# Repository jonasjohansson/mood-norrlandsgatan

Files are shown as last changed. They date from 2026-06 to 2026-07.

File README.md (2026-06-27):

# Mood Norrlandsgatan — "People in Orbit"

CAD + browser tooling for the **AMF / Mood Gallerian** entrance light installation
(Norrlandsgatan, Stockholm), replacing Peter Hagdahl's *Liquid Sky*. Glowing
human-like bodies that orbit the entrance columns, made of LED-in-silicone flex
pushed into a **glossy snap-groove host**, bracketed to the **existing ceiling
steel profiles**. Canopy ≈ **9 × 5 m**. Brief: 10-yr life, low maintenance, fire
(PBL — bygglov granted).

## Settled spec (assumptions until supplier confirms)
- **Light:** FN-ESJT-B0612 **6×12 COB**, **white LED in coloured silicone** — colour
  is a stable pigment, no RGB controller (the *Liquid Sky* lesson: minimal electronics).
  Fixed colour per figure; 2-core + white driver. Min bend radius assumed **90 mm**.
- **Host:** glossy panel with a routed **dovetail snap-groove** (undercut grips the
  6 mm foot; 12 mm body + dome hang down, light into the room).
- **Material:** exterior **compact phenolic** (Trespa Meteon / Fundermax), high-gloss
  — outdoor/UV/fire-rated, routable.
- **Cut:** **Shaper Origin** + dovetail bit, on-line along the figure paths.
- **Mount:** brackets to the existing steel profiles; modules with expansion gaps.

## The loop
```
figure .ai ─▶ Bend Lab (edit shape, all-green) ─▶ paths.json
   ─▶ shaper.py (1:1 dovetail-groove SVG)  ─▶ Shaper Origin cut
   ─▶ figure.py (3D canopy preview) · order.py (cut list / BOM)
```

## Layout
```
cad/
  channel.py    core params (HostParams = 6x12 profile), snap-groove, neon, coupon
  detail.py     engineering detail: dovetail snap + bracket + steel profile
  options.py    mounting-option comparison (groove vs alu track vs clips)
  figure.py     full 9x5 m canopy module -> STL/STEP + manifest (reads paths.json)
  svgcheck.py   bend-radius check on a figure SVG -> overlay + paths.json
  shaper.py     1:1 mm Shaper Origin cut SVGs (on-line dovetail grooves)
  order.py      procurement cut list: metres per colour, segments, power
  calibrate.py  neon snap-fit coupons across slot clearances
  render.py     headless STL -> PNG
  index.html    3D viewer (light, static): toggles + explode
  bendlab.html  SHAPE + BEND editor: load/draw, edit anchors, smoothing slider,
                break-at-fingers, live bend check, export SVG + paths.json
  ideate.html   (optional) freehand pattern sketcher
  out/          exports + manifest.json + order.csv  (gitignored)
```

## Use
Served by the local web server (docroot = `~/Documents/GitHub`):
```
  bend lab:  http://localhost/mood-norrlandsgatan/cad/bendlab.html   (edit a figure -> Export)
  3D view:   http://localhost/mood-norrlandsgatan/cad/               (run figure.py first)
  bend map:  http://localhost/mood-norrlandsgatan/cad/out/check_<name>.svg
```
```sh
cd cad
uv run python figure.py         # canopy preview  (or detail.py for the snap detail)
uv run python shaper.py         # 1:1 groove SVGs for the Origin
uv run python order.py          # cut list / bill of materials
uv run python calibrate.py      # snap-fit coupons to tune the push-fit
```

## Parameters (`cad/channel.py` → `HostParams`, mm)
| param | default | meaning |
|---|---|---|
| `neon_w` / `neon_h` | 6 / 12 | FN-ESJT-B0612 foot width / full height |
| `foot` / `slot_depth` | 5 / 5 | foot gripped in the groove / groove depth |
| `slot_clr` | 0.4 | per-side push-fit clearance — **tune with `calibrate.py`** |
| `lip` | 1.0 | undercut retaining lip (dovetail bit) |
| `panel_t` | 12 | glossy host thickness |

## To confirm with the supplier / site
- [ ] FN-ESJT-B0612 **COB availability**, **silicone jacket colours**, IP rating, **real min bend radius**.
- [ ] White LED **CCT** (tunes the filtered colour) + output (colour filter costs brightness).
- [ ] Steel-profile section/spacing on site → bracket type + `PROFILE_YS`.
- [ ] Real figures: edit in Bend Lab to all-green, export `paths.json`.
- [ ] Sweep the dovetail groove along curved paths (today exact only on the straight detail/coupon).

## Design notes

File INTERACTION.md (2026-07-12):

# Interaction — touch the pillars, the figures come alive

## Concept
A conductive **hand-sign plate** on each of the 2 entrance pillars. The figures **rest at
~50% brightness** all the time; place a hand on a plate and they **rise to ~90% and hold**
there while the hand rests, easing back to 50% when it lifts. A short onset ripple sweeps up
from the touched pillar as the light rushes in. Non-addressable coloured neon, animated by
**per-figure brightness (PWM)** — colours stay fixed, motion is in the dimming.

Presence is continuous (force sensing), so this is a level, not a trigger: partial pressure
could even map to a partial lift between 50% and 90%. Tunable live in the viewer via
**Neon → Rest level / Touch level**.

## Sensor — force sensing (hand rests with slight pressure)
Requirements: detect a hand *placed/resting*, **works with gloves**, bulletproof, IP-rated,
lasts years outdoors. -> **load cell / strain gauge behind the aluminium plate**
(HX711 amp -> ESP32), or an industrial piezo force switch for simple on/off.
- Gloves: irrelevant (mechanical force, not capacitance/optics).
- Weatherproof/vandal-proof: sensor fully sealed behind the solid plate; nothing exposed;
  millions of cycles.
- Continuous force -> detects presence *while held*; press hard = optional intensity map.
- Firmware auto-tracks baseline (zeroes plate weight + thermal drift), fires on threshold.
- NOT a no-contact hover (that needs optical/ToF, whose window fouls over years).

## Electrical topology
    pillar plate ─ load cell ─ HX711 ─ sensor ESP32 (at pillar) ─ ESP-NOW ─┐
                                                                           ▼
    24 V PSU(s) ──▶ 8-ch MOSFET board (main ESP32, LEDC PWM) ──▶ figure channels
                         ▲ per-figure feeds converge here (see channels.json)

- Put the sensor node **at the pillar** (short load-cell lead); send touch events to the
  ceiling controller over **ESP-NOW** (no data cable up the pillar).
- Main ESP32 in the plenum drives one logic-level MOSFET per channel (size ~10 A each).

## Channels (see `channels.py` / `out/channels.json`)
8 channels (7 figures + rings), ~1122 W / 47 A @ 24 V. Biggest: blue 8.2 A.

## Added BOM (interaction only)
- 1x main ESP32 + 8-ch logic-level MOSFET board (or 8 discrete IRLZ44N-class FETs + gate R)
- 2x pillar sensor node: ESP32 (or ESP8266) + HX711 + load cell/strain gauge
- 2x aluminium hand-sign plate + isolating standoffs + flexure/mount for the load cell
- IP67 enclosures, glands, a bit more DC cable to converge feeds at the MOSFET board

## Open items
- Confirm strip **W/m** from datasheet (tightens W/A above).
- Choose load cell range (a light hand press is ~1-5 kg-equivalent on the plate).
- Animation design: ripple-from-pillar, all-breathe, per-figure chase (all doable in PWM).

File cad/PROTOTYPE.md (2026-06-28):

# Mounting prototype — first physical test

Goal: prove the **snap-fit** and the **bend** before cutting a full sheet.

## You need
- A **panel offcut** — ideally the real exterior compact phenolic (Trespa/Fundermax);
  any flat board (MDF/acrylic) is fine for a first dry run.
- The **Shaper Origin** + a **dovetail bit** (undercut groove). For a quick first
  pass a straight bit ~0.5 mm under the flex width also friction-fits.
- A few metres of **FN-ESJT-B0612** (6×12 COB) — the actual flex.
- A **steel offcut** + a **bracket / channel-nut** (to test the connection + overhead hold).

## Cut the coupon
File: `out/shaper/coupon.svg` (1:1 mm) →
`http://localhost/mood-norrlandsgatan/cad/out/shaper/coupon.svg`
- Import to the Origin, **On-Line** cut, **Shaper Tape** to register.
- 3 straight grooves = dial in **bit + depth + fit**.
- Arcs **r=120 / 90 / 60 mm** = bend test (90 = assumed min; 60 should kink/fail).
- Start depth ~**6 mm** (grips the foot; dome stays proud). Adjust on the straights.

## Test
1. Push the flex into the straight grooves — find the depth/fit that **holds when held upside-down** (overhead is the real test).
2. Run the flex around the arcs — confirm **90 mm** is clean; note where it kinks.
3. Bolt the coupon to the steel offcut with the bracket; **hang it**, power the flex.
   Check: overhead hold, the glow/line look, and gloss reflection off the panel.

## Report back → bake into the model
Tell me what worked and I'll set it in `channel.py → HostParams`:
- the **bit** (width) and **groove depth** that held,
- the **real min bend radius** (set the Bend Lab slider + `svgcheck.py` to it),
- the **bracket type** + spacing that felt solid.

Then `calibrate.py` / `shaper.py` regenerate against the proven numbers.

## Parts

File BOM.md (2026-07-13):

# Electrical BOM — People in Orbit (24 V)

_Auto-generated by `bom.py` from the current design. Load: **1122 W / 46.8 A @ 24 V**, 112 m neon, 28 power feeds, 10 continuous runs, 570 clips._

## Load per channel (one PWM channel / MOSFET per colour)

| colour | length | power | current | feeds |
|---|---|---|---|---|
| blue |  19.7 m |  197 W |  8.2 A | 4 |
| green |  16.2 m |  162 W |  6.8 A | 4 |
| yellow  |  16.2 m |  162 W |  6.8 A | 4 |
| cyan |  15.5 m |  155 W |  6.4 A | 4 |
| pink |  11.7 m |  117 W |  4.9 A | 3 |
| orange  |  11.5 m |  115 W |  4.8 A | 4 |
| purple  |  11.4 m |  114 W |  4.8 A | 3 |
| rings |  10.0 m |  100 W |  4.2 A | 2 |
| **total** | **112 m** | **1122 W** | **46.8 A** | **28** |

## Power supplies

- **5 x Mean Well HLG-320H-24 (320 W, IP67, 24 V)** — 1600 W installed vs 1122 W load (~70 % loaded). Mount distributed up near the soffit, each feeding its local zone — keep 24 V DC runs short. Dimming is downstream (MOSFET PWM), so a plain constant-voltage supply is fine.

## Control

- **1 x ESP32** (ceiling) — 8x LEDC PWM -> 8 MOSFETs, common-anode (switch the 24 V return).
- **8 x IRLB3034PBF** logic-level N-MOSFET (or an 8-ch >=16 A trigger board) — blue channel peaks 8.2 A, so size gate drive + heatsinking for >=10 A.
- **2 x ESP32 + HX711 + load cell** at the pillars — force-sensing hand-plates, ESP-NOW to the ceiling node.

## Neon terminations & mounting

- **28 feed connectors** (IP67) at the injection points + **~20 end caps** for the run ends.
- **639 stainless back-clips** for the through-slot mounting (incl. spare).

## Cable (estimated — refine against final PSU placement)

- **~118 m** 2-core 2.5 mm2 for 24 V distribution (PSU -> 28 feeds).
- **~40 m** mains + fused spur to the 5 supplies.

## Rough cost (electronics only — excl. Trespa panels, aluminium structure, labour)

| item | est. |
|---|---|
| Neon 24 V silicone flex, coloured (per profile), +12 % | $314 |
| Mean Well HLG-320H-24 (320 W, IP67, 24 V) | $300 |
| ESP32 dev board (1 ceiling controller + 2 pillar sensors) | $24 |
| 8-ch logic-level MOSFET (IRLB3034PBF) + heatsinks/gate res. | $42 |
| Load cell + HX711 amp (per pillar) | $30 |
| IP67 neon feed connectors / end caps | $114 |
| Stainless back-clips (through-slot mounting) | $160 |
| 2-core DC distribution cable 2.5 mm2 | $130 |
| Mains cable + fused spur to PSUs | $56 |
| Heat-shrink, WAGO, ferrules, cable clips, misc | $120 |
| **subtotal** | **$1,290** |

_Order-of-magnitude USD; confirm against suppliers. Neon @ ~$2.5/m, PSU @ ~$60. Excludes the boards (Trespa), aluminium ceiling profiles, and install labour._

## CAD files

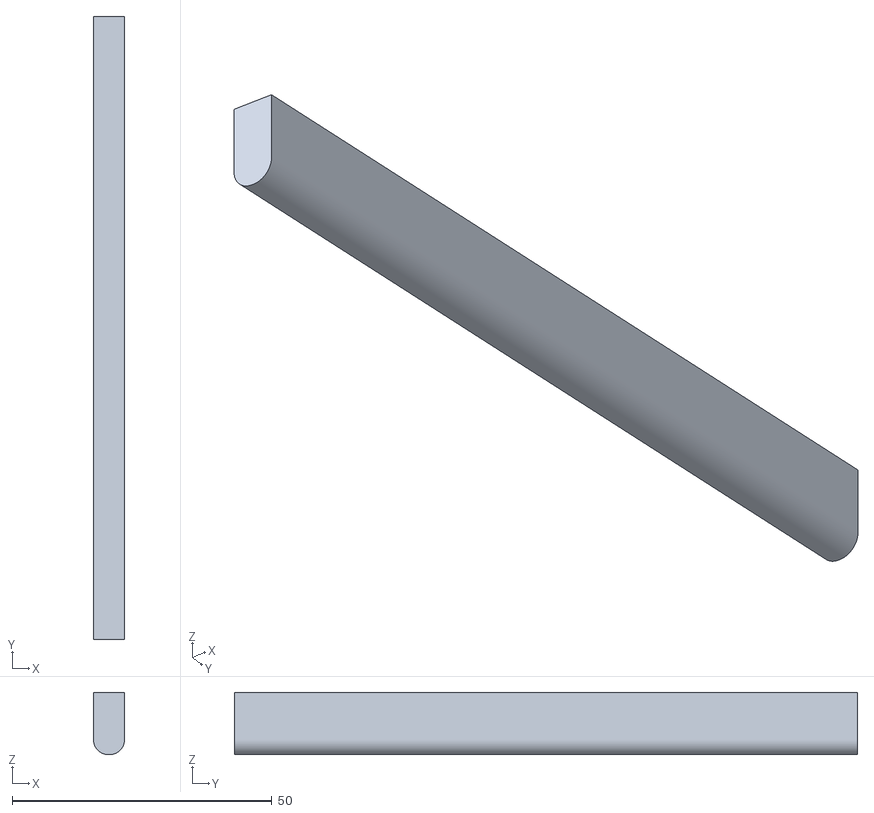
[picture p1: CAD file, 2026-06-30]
out/opt_C_neon.stl
6.00 x 120.0 x 12.0

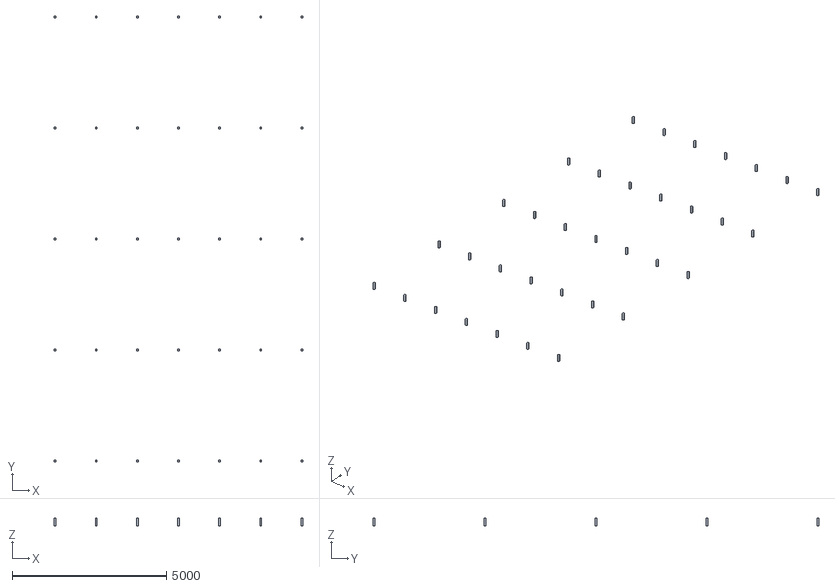
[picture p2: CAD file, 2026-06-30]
out/brackets.stl
8057.5 x 14455.3 x 250.0

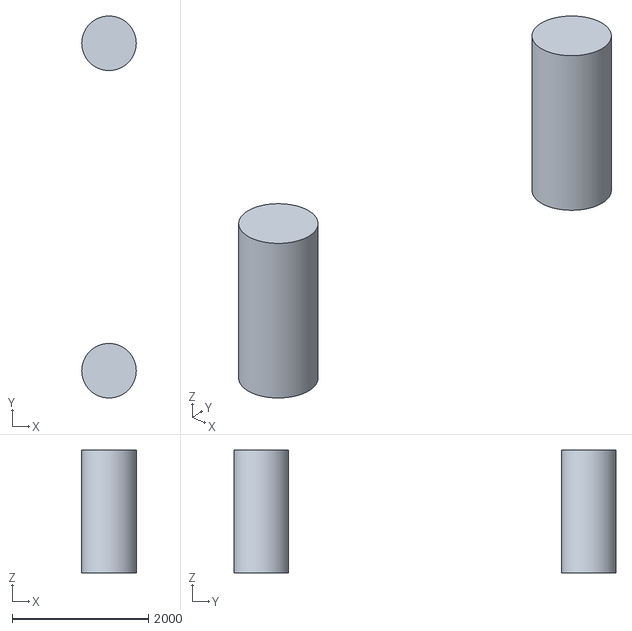
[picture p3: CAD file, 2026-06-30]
out/columns.stl
800.0 x 5602.8 x 1800.0

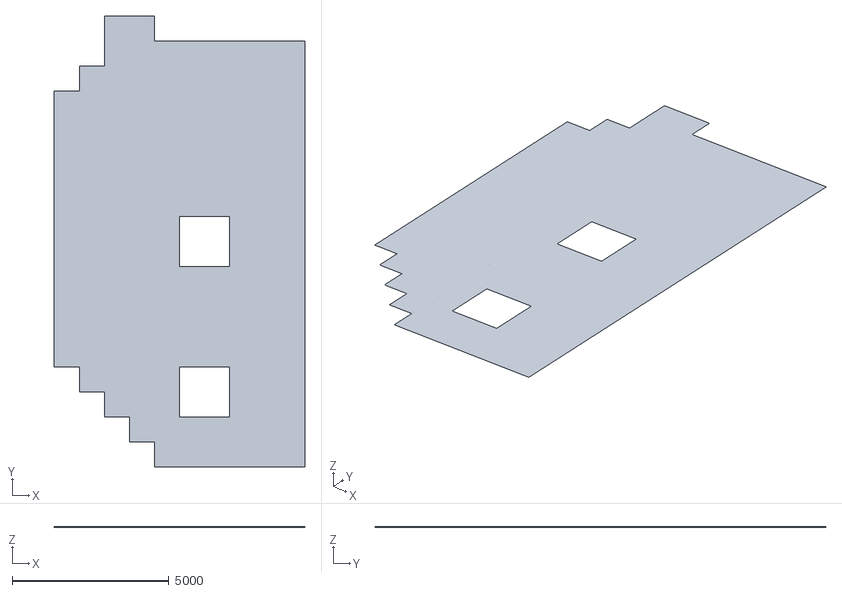
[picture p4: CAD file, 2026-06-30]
out/host.stl
7997.5 x 14395.3 x 12.0

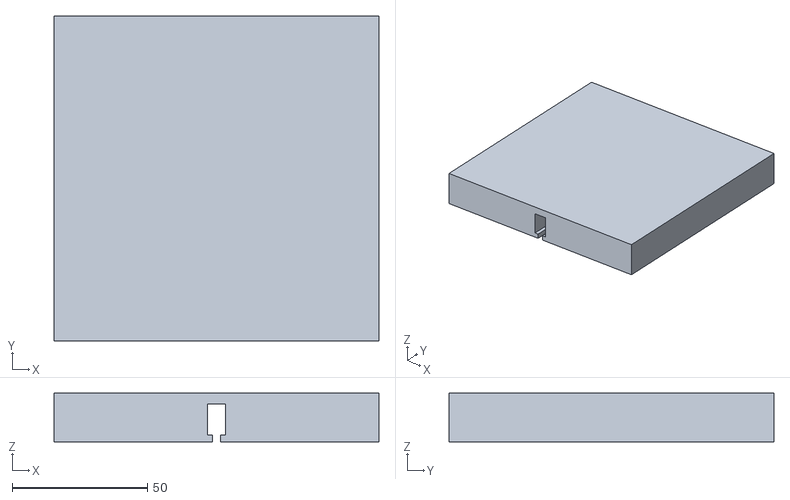
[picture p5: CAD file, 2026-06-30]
out/opt_A_glossy_host.stl
120.0 x 120.0 x 18.0

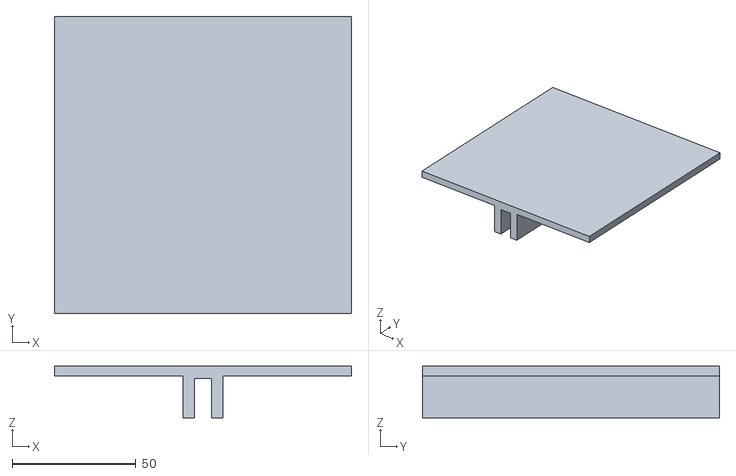
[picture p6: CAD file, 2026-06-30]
out/opt_B_alu_track.stl
120.0 x 120.0 x 21.0

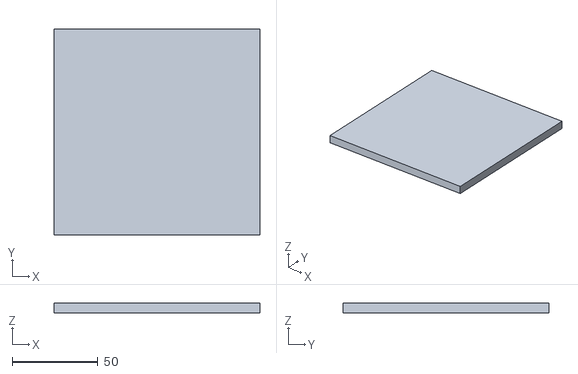
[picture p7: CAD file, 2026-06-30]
out/opt_C_plate.stl
120.0 x 120.0 x 6.00

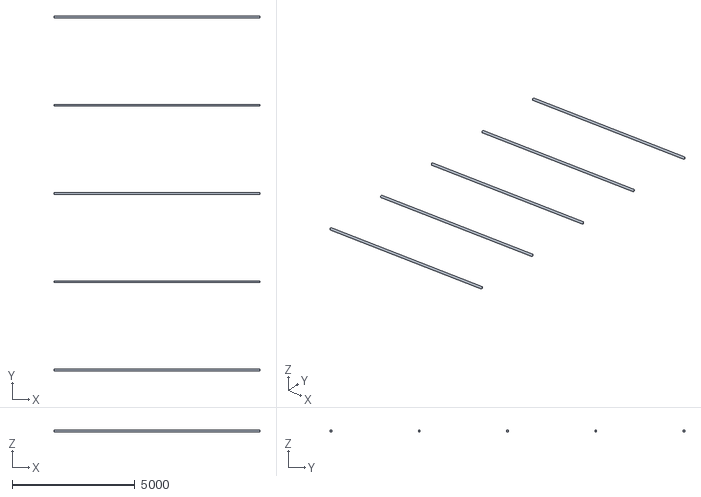
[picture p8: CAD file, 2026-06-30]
out/steel.stl
8397.5 x 14475.3 x 80.0

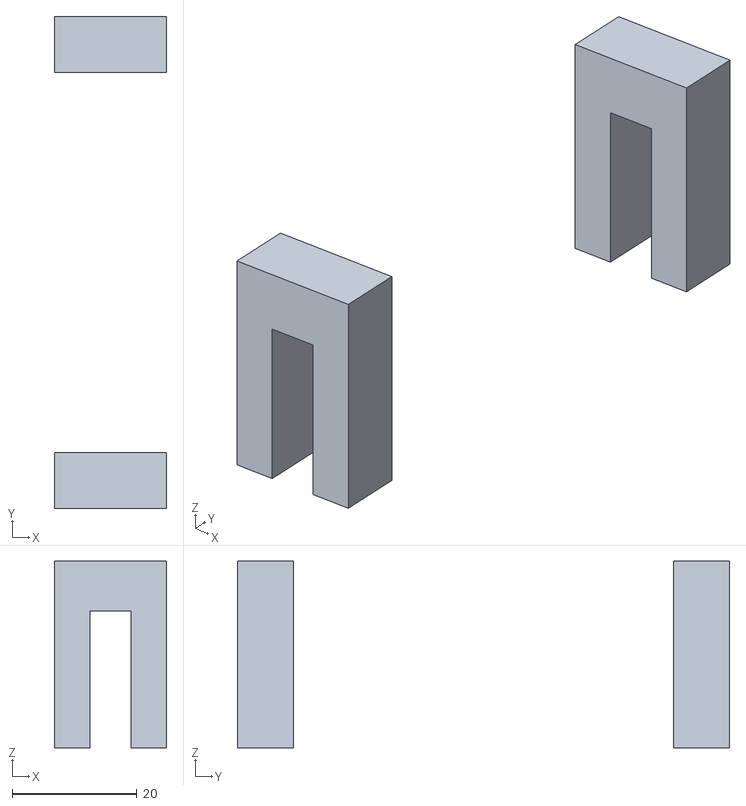
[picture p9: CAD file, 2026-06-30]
out/opt_C_clips.stl
18.0 x 79.0 x 30.0

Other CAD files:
out/opt_B_neon.stl
out/opt_A_neon.stl

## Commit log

2026-06-26 Scaffold mood-norrlandsgatan: parametric LED-channel CAD + Three.js viewer
    build123d source (channel/figure/calibrate/render) models the channel-letter
    tray system; exports STL+STEP+manifest.json to out/ (gitignored); index.html
    viewer with per-part toggles, explode and bloom glow.
2026-06-26 Engineering focus: real FN-ESJT-B1023 neon, dovetail snap detail, light static viewer
    - channel.py HostParams: real product dims (10x23 dome neon, 6 mm foot grip, 12 mm host)
    - detail.py: clear engineering detail — undercut dovetail groove + bracket + steel
    profile (the part to ideate the mounting on), neon modelled with rounded dome
    - index.html: light background, NO animation, matte materials so everything is
    visible; explode separates neon/bracket/steel for inspection
    - README: real product + engineering detail + figures come from the .ai files
    - browser smoke-tested assembled + exploded (no JS errors)
2026-06-27 Add svgcheck.py: LED-flex bend-radius check for figure SVGs
    Samples an SVG body outline, computes local radius of curvature, flags spots
    tighter than the 150 mm min bend radius, reports min feasible size + LED run
    length, writes a green/red overlay + paths.json. On "Asset 1" (a body): 28% of
    the outline is too tight (fingers/face/feet) — gesture is fine, extremities need
    simplifying.
2026-06-27 Bend Lab -> shape editor: adjust the figure live, then export
    - Loaded/drawn figures become editable anchor points: drag to reshape, double-click
    to add, alt/right-click to delete, Simplify to strip detail, Figure-width to scale.
    - Live bend feedback (tightest / too-tight% / length) + min-radius ring.
    - "Break at tight bends" segments at the fingers etc.; Export (SVG + paths.json)
    honors it, so the broken pieces are what goes to shaper.py/figure.py.
    - Smoke-tested: load, simplify, drag, segment, export — no JS errors.
2026-06-27 Settle on 6x12 COB / coloured-silicone profile + add order.py cut list
    - HostParams -> FN-ESJT-B0612 6x12 (neon_w 6, neon_h 12, foot/slot 5, lip 1.0);
    Bend Lab default min radius -> 90 mm to match.
    - order.py: procurement cut list — per-figure length/colour/segments, metres &
    reels per colour, total power + PSU sizing; writes out/order.csv.
    - README refreshed to the settled spec (white LED in coloured silicone, no
    controller) and the full bendlab -> shaper -> order loop.
2026-06-27 Run the current figure (Asset 1) end-to-end
    - svgcheck.py: low-pass box-smoothing tied to the bend radius + auto-simplify, so a
    detailed figure becomes a buildable smoothed outline; writes canonical out/paths.json.
    - order.py: measure curvature at fixed 25 mm spacing (kills dense-sampling noise) —
    segment count went 580 -> 16 (real).
    - figure.py: thin() dense paths before building neon (OCC trace failed on 100s of
    points); per-body try/except. Canopy now builds all bodies.
    - Result @4.5 m: ~all-green, 16 feeds, 17.6 m flex, ~176 W.
2026-06-27 viewer: default camera looks up at the underside so the figure is visible
2026-06-27 Use the real ceiling layout (Asset 8): 50 cm tile footprint + columns
    - ceiling_import.py: parse the layout SVG -> ceiling.json (tile centres in mm,
    column centres/radii, 9.0x5.0 m at 500 mm/tile).
    - figure.py: build the host from the real soffit footprint (union of 151 tiles)
    with the two column openings, true scale; figure sits in the real ceiling.
2026-06-27 Bend Lab -> composition tool: ceiling backdrop + place/scale/rotate, human-scale default
    - Loads ceiling.json as a backdrop (50 cm tiles + columns), view auto-fits the soffit.
    - Move mode (drag whole figure), Rotate slider (about centroid), Figure-width scales
    about centroid; default figure width 2.2 m (human scale). Transforms bake into the
    anchors so Export carries the placement into paths.json.
    - Smoke-tested: backdrop + load + move + rotate, no JS errors.
2026-06-28 Bend Lab: predrawn figure auto-loads on the ceiling (Move mode)
    - Embed the figure in the repo (cad/figures/asset1.svg) and auto-load it on
    startup, so it's already placed on the ceiling backdrop at human scale.
    - Default to Move mode so the first view is clean (no anchor clutter) and the
    figure is ready to drag into position.
2026-06-28 Add Shaper test coupon + prototype guide for the mounting
    shaper_coupon.py -> out/shaper/coupon.svg (straight grooves + r=120/90/60 arcs);
    PROTOTYPE.md: cut it on the Origin, push the flex, test overhead hold + bend,
    report numbers back to bake into HostParams.
2026-06-28 viewer: overlay the 2D ceiling layout (tile grid + column circles) in 3D
    addGrid() reads ceiling.json and draws the 50 cm tile grid + column circles on the
    ceiling underside, with a 'ceiling grid' toggle — figure, columns and grid together
    at real scale.
2026-06-28 viewer: lil-gui settings panel, flush neon, integrated CAD views
    - Rebuilt the viewer UI around lil-gui (minimal, foldered): View, Mode, Explode,
    Glow (bloom/neon), Surface (host colour/roughness/metalness), Neon (seat/flush),
    Layers (per-part), Camera.
    - Neon "seat" control seats the neon flush in the host (default 1 mm proud).
    - View switcher loads canopy / mounting detail / mounting options without re-running
    scripts (figure.py/detail.py/options.py now also write named manifests).
    - browser smoke-tested all views + modes, no JS errors.
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2026-06-29 viewer: building in canopy frame + alignment sliders
    - Re-exported building GLB Z-up (Blender) so it shares the canopy coordinate frame
    (fixes the funky orientation); building now loaded under root, scaled m->mm.
    - Added Building-align GUI folder (X/Y/Z/Rotation/Scale) to dial the building onto
    the real two pillars by eye; fit() excludes the building so framing stays on the art.
2026-06-29 Scale the artwork to the survey building (2-pillar registration)
    - svgcheck.py: register the composition's two column circles onto the building's two
    pillars (scale+rotate+translate) -> figures at true scale/orientation in the
    building frame; paths.json now real-scale (~181 m LED).
    - ceiling.json registered the same way -> 14.4 x 8.0 m (matches the .blend mood-04
    plane), columns on the pillars; real tile size ~80 cm (not 50).
    - Reset building-align to identity (building real size, canopy fits it).
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2026-06-29 viewer: realistic scene — environment light, reflective floor, eye-level camera
    - scene.environment via PMREM RoomEnvironment (soft reflections + ambient on every
    surface); per-mode environmentIntensity + fog.
    - Reflective floor (THREE.Reflector) 3 m below the soffit -> neon reflects (wet street).
    - Live preset brighter (dusk) so the building/pillars read while neon still pops.
    - Eye-level camera (standing on the floor looking up); "Stand under" button; Floor toggle.
    - Fixed Reflector colour via shader uniform (not material.color).
2026-06-30 viewer: stand the building on the floor (pillar bases at y=0)
    Shift root so the building's base sits on the floor at y=0 (was centred on the
    soffit, so pillars hung through the floor); soffit + figures sit up at clearance
    height. Floor at 0, eye-level camera backed off to a street view looking up.
    Reset on view-switch.
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2026-06-30 viewer: remove ceiling light-blobs + de-blue the floor
    - Removed the magenta/purple spill point-lights (they splashed hotspots on the
    soffit) and made the soffit matte (roughness 0.88) so it no longer mirrors the HDRI.
    - Floor envMapIntensity 0.15 + neutral dark colour + warm hemi ground + lower env
    → floor reads as dark pavement instead of catching the blue night sky.
2026-06-30 viewer: walk camera + night sky by default, GUI cleanup
    - Default to walk (FPS) camera in the canopy view, standing on the ground looking up
    at the lit soffit; Mode defaults to live, Night sky (HDRI) on.
    - Fixed fit(): update world matrices before measuring so the camera target uses the
    building's ground-shift (was aiming down at y -729 → horizon; now aims up).
    - GUI reorganised: View/Mode, then Camera, Scene, Neon, Material(+Specs),
    Engineering(+Building align, collapsed), and Layers LAST (collapsed).
2026-06-30 figures: fix orientation (mirror + 180deg pairing)
    The 2-pillar fit has 4 placements; the plan is mirrored on the soffit (viewed from
    below) AND the pillar pairing was reversed. Registered the .ai OUTLINE under all 4 and
    matched it to the real soffit footprint: REFLECTION + SWAPPED pairing lands the OUTLINE
    centre on the soffit (d=52 mm vs 1238-5005 mm for the others). svgcheck now uses that
    (complex conjugate similarity, swapped targets). Figures read correctly now.
2026-06-30 viewer: render neon as tubes from paths.json (all figures show + faster)
    The build123d sweep dropped 3 dense/self-intersecting body outlines (the big pink &
    yellow figures), so they vanished. The viewer now builds neon as Three.js TubeGeometry
    straight from paths.json instead of loading the OCC STLs: every figure renders (no sweep
    failures), per-figure colour preserved, and load is much faster (no multi-MB neon meshes).
    STLs remain for fabrication.
2026-06-30 deploy: publish runtime out/ files for GitHub Pages; ignore stale/heavy outputs
    [brackets.stl, columns.stl, host.stl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]
2026-06-30 viewer: host panel hangs below the soffit and stays visible with the building
    The host was extruded above the ceiling plane (hidden behind the opaque soffit) and
    auto-hidden when the building showed. Now it hangs at -seat (figures on its underside)
    and is no longer hidden by the building toggle -> the mounting panel is visible.
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2026-07-02 fabrication: per-panel export (through-slot + back-clip method)
    export_panels.py -> out/panels/: per-panel 1:1 mm SVG (outline = supplier shape upload,
    channels = Shaper through-slots, clips = back-clip screw holes ~200mm, power = feed points),
    plus _key.svg placement map + schedule.csv. Also out/clips.json for the viewer.
    Viewer draws green clip points + magenta break/power points on the panels layer.
    Totals: 39 panels, 111 m LED, 250 clips, ~98 junctions.
    [schedule.csv]
2026-07-02 panelize_mixed: brick bands + per-band DP seam placement (65 panels, 81 breaks)
    1.0 m bands, panel widths in 0.5 m modules (0.5-2.0 m, always adding up across the row);
    a DP places each vertical seam where it crosses the fewest figure lines. Beats uniform
    2x1 m on both counts (65 vs 68 panels, 81 vs 98 breaks). Mostly 2x1 bricks with 1.5/1.0/
    0.5 fillers under dense figures. Re-exported per-panel package (33 figure panels, 111 m
    LED, 221 clips, 162 feeds).
    [schedule.csv]
2026-07-03 panelize v2: portrait merges + stub-aware seams + thin-web bridge marking
    - Portrait pass: where figures cross a horizontal band line, the two stacked panels are
    locally re-tiled into portrait boards (<=1.0 m x 2 bands) that swallow the seam;
    accepted only where breaks drop. 7 portraits -> 64 -> 57 breaks.
    - Seam DP penalizes cuts that leave LED pieces <150 mm (stubs 10 -> 9; rest are
    figure-geometry-driven and flagged).
    - export_panels marks thin-web spots (<26 mm between slots) as amber bridge points in
    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
    [schedule.csv]
2026-07-03 optimize_layout v3: joint shrink+slide search (44 breaks, 60 panels)
    Scale and translation now searched together per figure (shrink-and-slide as one move,
    floor 0.84), fixing the miss the user spotted: figures poking just past a sheet edge.
    Fresh run from original geometry, vertical bands: 60 panels (43 identical 1x2 m),
    44 breaks, 78 pieces, 101 m LED (was 67/45/79/109). Green tucked inside its sheets at
    0.84/-6deg exactly as suggested. Prior geometries kept: paths_vertical_v1.json,
    paths_horizontal_opt.json, paths_prenudge.json (original).
    [schedule.csv]
2026-07-03 viewer: render the actual sheets (60 boards + joint gaps) instead of monolithic host
    Plan/live now draw one 6 mm board per panel from panels.json with a 6 mm joint gap,
    at the neon plane (dome flush through the slot). Material (host panel) controls drive
    all boards; monolithic CAD host skipped in the canopy view. Sheets stay visible with
    the building.
2026-07-03 outline_close: continuous closed figure outlines, drop interior detail
    Per figure: drop strokes <200 mm (mouths/marks/interior bits), merge fragments whose
    endpoints are within 500 mm into continuous outlines (bridging the drawn gaps), and
    close each chain into a loop where its own ends are within 500 mm. No cross-body jumps
    (large gaps left as separate limb strokes). 30 strokes -> 10 bodies.
    Downstream win: LED pieces 78->52, stubs 10->1, breaks held at 44, 102 m LED.
    Pre-close geometry kept at out/paths_fragmented.json.
    [schedule.csv]
2026-07-03 one figure per sheet: shared-panel conflict eliminated
    Added shared-panel conflict counting to optimize_layout's objective (conflicts first,
    then MINIMAL change, then breaks). Only 2 panels had 2 figures (purple overlapping green
    and orange); cleared with two 100 mm slides (orange +100, purple +100) - no scaling, no
    rotation, breaks unchanged. Verified 0 conflicts on the real portrait-merged panelize:
    63 panels, 44 breaks, 52 pieces, every sheet carries at most one figure.
    [schedule.csv]
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2026-07-12 viewer: seat touch-plates flush on the pillar faces + "Go to touch plate" camera button
    Plates were buried inside the pillar (offset too small) and the default
    look-up view hid them. Now placed on the +Z street-facing surface at the
    measured pillar radius (~490mm), hand height, with a camera shortcut.
2026-07-12 interaction: hold model — figures rest at 50%, hand on plate lifts to 90% and holds
    Replaces the one-shot ripple with a sustained presence level (matches the
    continuous force sensor): eased ramp up while a hand rests, ease back on
    release, brief onset ripple as the light rushes in. Rest/Touch levels are
    live-tunable in the Neon folder.
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2026-07-13 panelize: expose CS/BH/WMAX/BETA as env knobs (defaults unchanged)
    Now that continuous neon runs across joints, seams no longer break the neon, so
    BETA (crossing penalty) becomes a design knob: BETA=0 optimises boards purely for
    handling. Sheet count is area-bound (~61-63 at 1x2m one-person), so default keeps
    the current seam layout — the knobs just make bigger/handling-only easy to sweep.
2026-07-13 electrical: switch to 12 V — ~2.5 m runs, double the feeds & current
    12 V neon-flex halves the max continuous run (5 m -> 2.5 m) and doubles current
    for the same wattage. channels.py is now voltage-aware (VOLTS/MAXRUN), computes
    feeds from continuous run length (not obsolete seam breaks), and reports A/feed.
    Viewer feed spacing dropped to 2.5 m. Result: 1122 W, 94 A @ 12 V, 49 feeds.
2026-07-13 electrical: BOM sized for 24 V (bom.py -> BOM.md)
    Reverted the working voltage to 24 V (channels.py + viewer feed spacing 5 m).
    Added bom.py: computes the full system bill from channels.json/clips.json/
    paths.json — 1122 W / 47 A, 5x HLG-320H-24, 28 feeds, 639 clips, ~118 m DC
    cable, ESP32 + 8x MOSFET, 2x load-cell sensor. Writes BOM.md (~$1.3k
    electronics, excl. panels/structure/labour). order.py stays the neon cut list.
2026-07-13 tool: neon-check.html — design checker against real neon constraints
    Companion to Illustrator: loads figures/composition.svg, auto-scales from the
    two ring circles (4803mm apart), renders the neon at true profile width, and
    flags cut points (bends tighter than min radius — cuts are fine, per the brief)
    and too-close spots (lines that physically cannot fit). Live sliders for width /
    min bend / min gap, pan+zoom, reload button. Uses native getPointAtLength so it
    handles any Illustrator path (beziers, CSS-class strokes).
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2026-07-13 neon-check: fixed-step gaussian smoothing (no facets), cap 300mm
    Smoothing resamples at a fixed ~6mm output so curves stay round at any amount
    (the old step scaled with the amount → faceted joints that read as false cuts).
    Note: smoothing rounds the body but cannot fix sub-neon-width detail (fingers) —
    that needs geometry simplification, not filtering.
2026-07-13 neon-check: Simplify = point reduction (RDP + centripetal Bezier), not blur
    Reframed "smooth" to its real purpose: optimise the anchor count while keeping
    the shape (hands untouched). RDP drops redundant points to a mm tolerance;
    centripetal Catmull-Rom renders/exports them as smooth Beziers with no overshoot.
    Stats show anchors + % reduction (6920 -> ~1370 at 6mm, -80%). Download emits a
    clean few-anchor Bezier SVG, ready to re-edit in Illustrator or feed the pipeline.
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
